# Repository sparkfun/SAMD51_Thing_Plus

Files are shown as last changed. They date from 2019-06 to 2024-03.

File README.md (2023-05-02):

SparkFun SAMD51 Thing Plus
========================================

SparkFun SAMD51 Thing Plus

[*SparkFun SAMD51 Thing Plus (DEV-14713)*](https://www.sparkfun.com/products/14713)

With a 32-bit ARM Cortex-M4F MCU, the [SAMD51 Thing Plus](https://www.sparkfun.com/products/14713) is one of our most powerful microcontroller boards yet! The SAMD51 Thing Plus provides you with an economical and easy to use development platform if you're needing more power with minimal working space. This Thing even comes flashed with the same convenient UF2 bootloader as the RedBoard Turbo. To make the Thing Plus even easier to use, we've moved a few pins around to make the board Feather compatible and it utilizes our handy Qwiic Connect System which means no soldering or shields are required to connect it to the rest of your system!

The ATSAMD51J20 utilizes a 32-bit ARM Cortex-M4 processor with Floating Point Unit (FPU), running up to 120MHz, up to 1MB of flash memory, up to 256KB of SRAM with ECC, up to 6 SERCOM interfaces, and other features. In addition to the USB interface and Qwiic connection, a The SAMD51 Thing Plus provides a 600mA 3.3V regulator and LiPo charger.

Repository Contents
-------------------

* **/Documentation** - Documentation (datasheet, graphical datasheet, etc.)
* **/Hardware** - Eagle design files (.brd, .sch)
* **/Production** - Production panel files (.brd)

Documentation
--------------
* [**Hookup Guide**](https://learn.sparkfun.com/tutorials/samd51-thing-plus-hookup-guide) - Basic hookup guide for the SAMD51 Thing Plus.
* [**SAMD51 Datasheet**](https://github.com/sparkfun/SAMD51_Thing_Plus/blob/master/Documents/SAMD51_datasheet.pdf)- Datasheet for the SAMD51 chip.
* [**Graphical Datasheet**](https://github.com/sparkfun/SAMD51_Thing_Plus/blob/master/Documents/SAMD51_Thing_Plus_graphical_datasheet_v01-02.pdf)- Graphical datasheet for the SAMD51 Thing Plus.

Product Versions
----------------
* [DEV-14713](https://www.sparkfun.com/products/14713) - Initial release of the SAMD51 Thing Plus.

Version History
---------------
* [V_1.0](https://github.com/sparkfun/SAMD51_Thing_Plus/releases/tag/v1.0.0) - Initial release of the SAMD51 Thing Plus.

License Information
-------------------

This product is _**open source**_! 

Please review the LICENSE.md file for license information.

If you have any questions or concerns on licensing, please visit the [SparkFun Forum](https://forum.sparkfun.com/index.php) and post a topic.

Distributed as-is; no warranty is given.

- Your friends at SparkFun.

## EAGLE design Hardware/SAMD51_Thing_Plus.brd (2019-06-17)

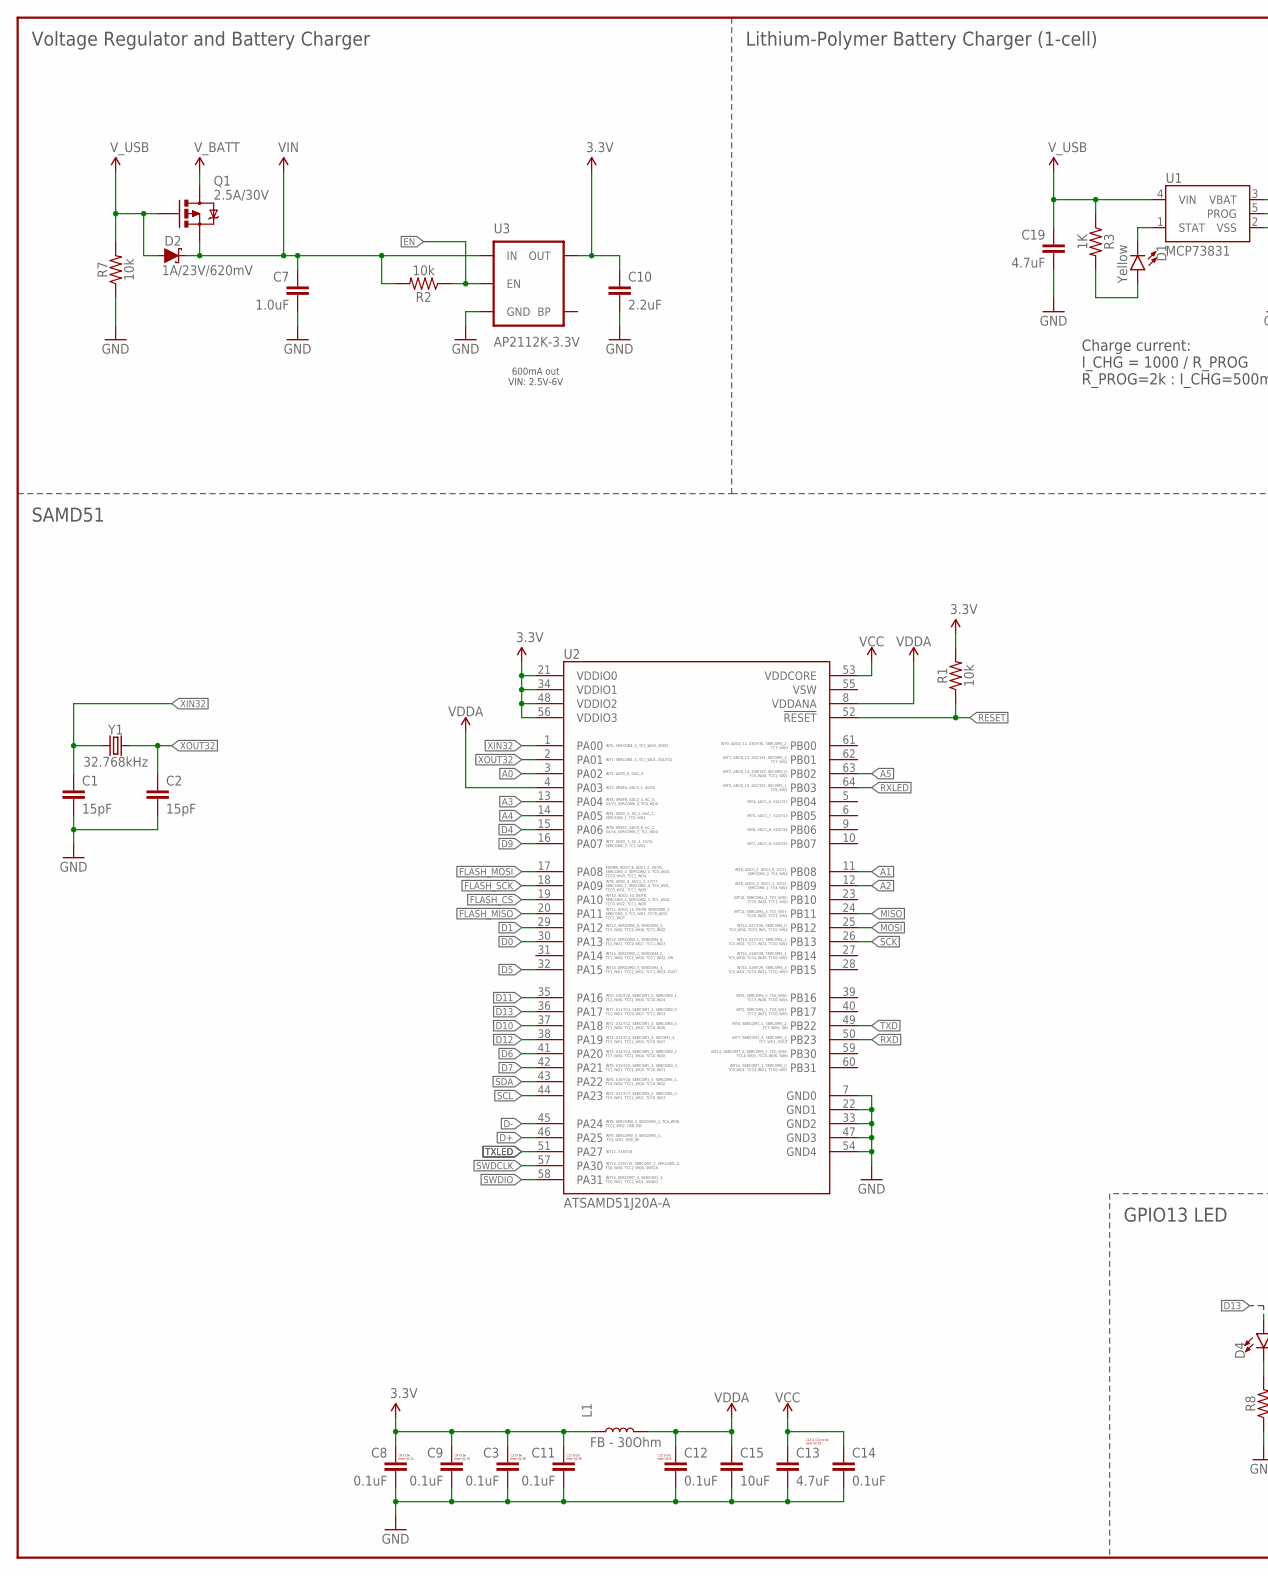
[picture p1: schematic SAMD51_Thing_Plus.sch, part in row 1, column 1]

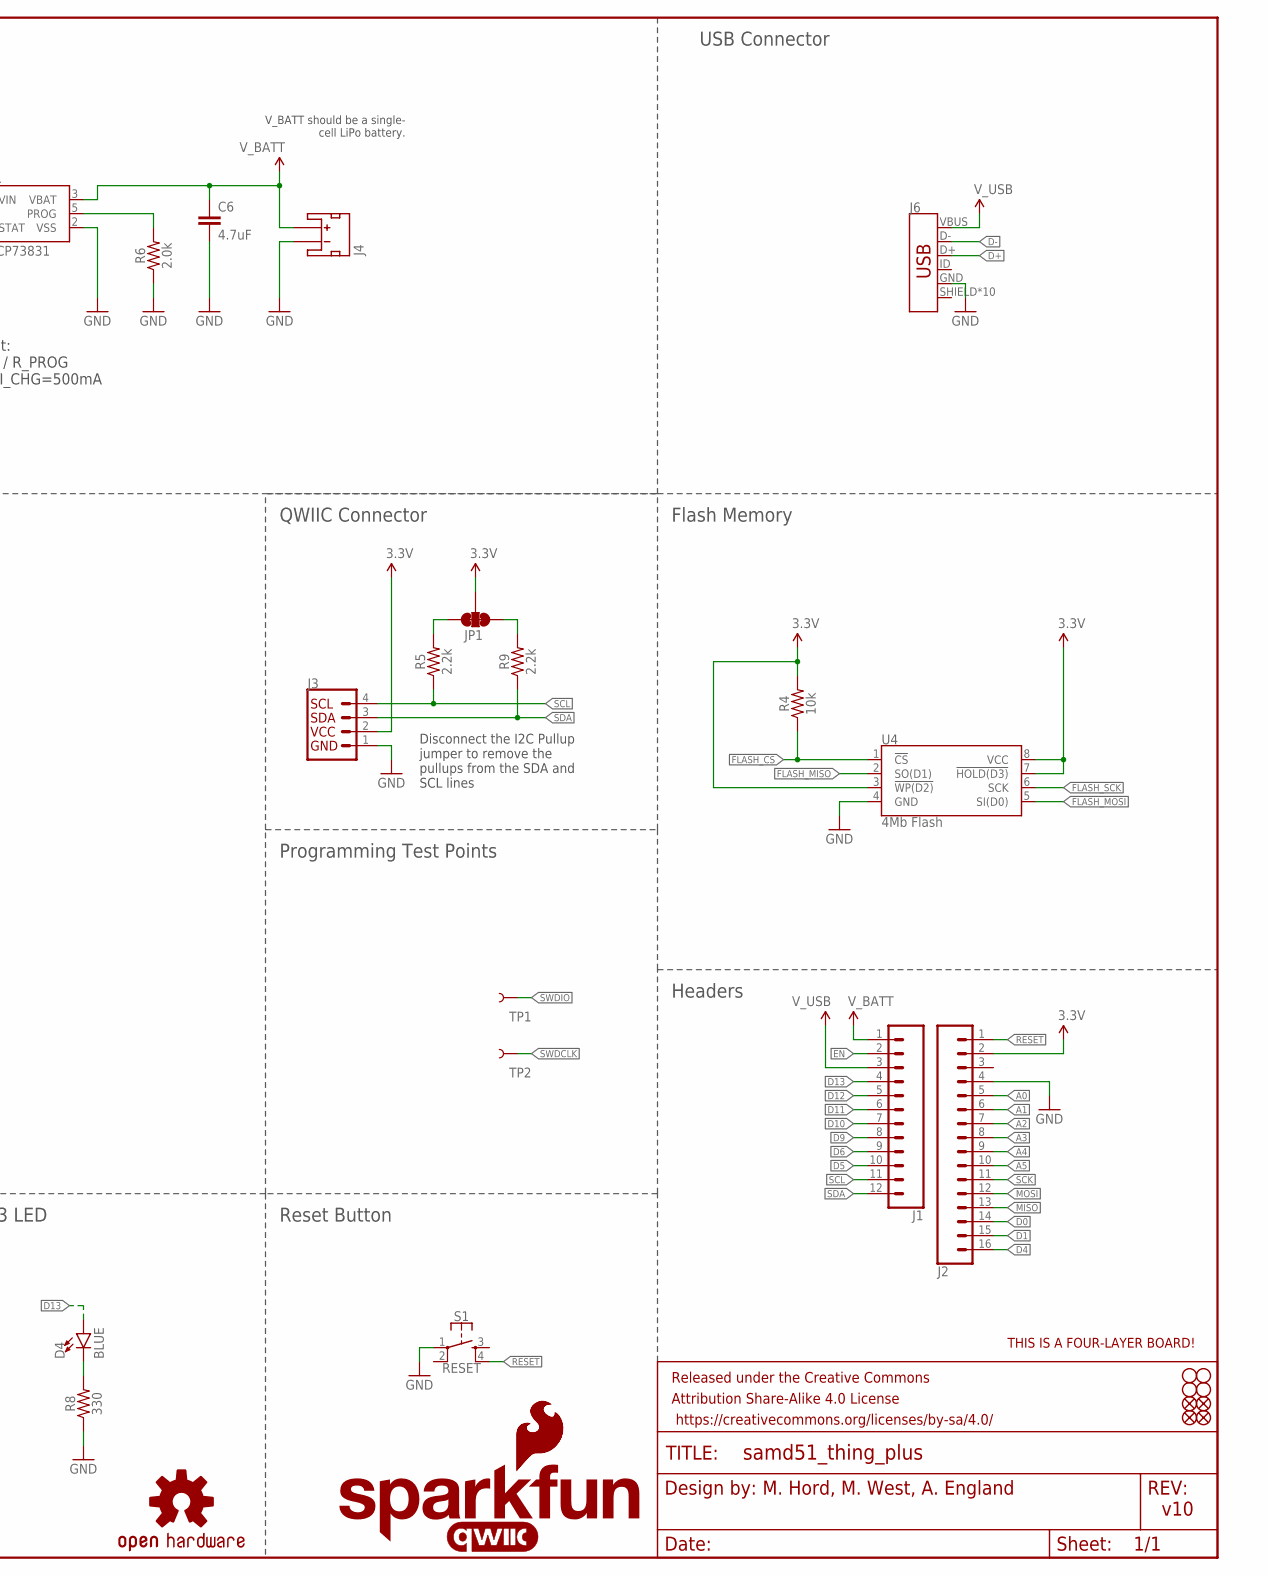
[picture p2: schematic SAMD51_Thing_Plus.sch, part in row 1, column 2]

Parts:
C1, C2: 15pF; 0402
C3, C8, C9, C11, C12, C14: 0.1uF; 0402
C6, C13, C19: 4.7uF; 0603
C7: 1.0uF; 0603
C10: 2.2uF; 0603
C15: 10uF; 0805
D1: Yellow; LED-0603
D2: 1A/23V/620mV; SOD-323
D4: BLUE; LED-0603
FD1, FD2, FD3, FD4: FIDUCIALUFIDUCIAL; FIDUCIAL-MICRO
FRAME1: FRAME-LEDGER; CREATIVE_COMMONS
H1, H2, H3, H4: STAND-OFF
J1: CONN_12SM_SQ_NO_SILK; 1X12_SM_SQ_NOSILK
J2: CONN_161X16_SM_SQ_NOSILK; 1X16_SM_SQ_NOSILK
J3: QWIIC_CONNECTORJS-1MM; JST04_1MM_RA
J4: JST_2MM_MALE; JST-2-SMD
J6: AMP FCI 10103594-0001LF; USB-MICROB-PTH-MILL
JP1: JUMPER-SMT_3_2-NC_TRACE_SILK; SMT-JUMPER_3_2-NC_TRACE_SILK
L1: FB - 30Ohm; 0603
LOGO1: FOUR_LAYER_WARNING
LOGO2: OSHW-LOGOMINI; OSHW-LOGO-MINI
LOGO3: SFE_LOGO_NAME_FLAME.1_INCH; SFE_LOGO_NAME_FLAME_.1
LOGO4: SFE_LOGO_FLAME.1_INCH; SFE_LOGO_FLAME_.1
Q1: 2.5A/30V; SOT23-3@1
R1, R2, R4, R7: 10k; 0603
R3: 1K; 0603
R5, R9: 2.2k; 0603
R6: 2.0k; 0603
R8: 330; 0603
S1: RESET; TACTILE_SWITCH_SMD_4.6X2.8MM
TP1, TP2: TEST-POINTTP_15TH_THRU; TP_15TH
U1: MCP73831; SOT23-5
U2: ATSAMD51J20A-A; TQFP64
U3: AP2112K-3.3V; SOT23-5
U4: 4Mb Flash; SO08
U$69: QWIIC_LOGO_5MM; QWIIC_5MM
Y1: 32.768kHz; CRYSTAL-SMD-3.2X1.5MM

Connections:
3.3V: C3.1, C8.1, C9.1, C10.1, C11.1, J2.2, J3.2, JP1.2, L1.1, R1.2, R4.2, U2.21 (VDDIO0), U2.34 (VDDIO1), U2.48 (VDDIO2), U2.56 (VDDIO3), U3.5 (OUT), U4.3 (!WP(D2)), U4.7 (!HOLD(D3)), U4.8 (VCC)
!RESET: J2.1, R1.1, S1.4, U2.52 (!RESET)
A0: J2.5, U2.3 (PA02)
A1: J2.6, U2.11 (PB08)
A2: J2.7, U2.12 (PB09)
A3: J2.8, U2.13 (PA04)
A4: J2.9, U2.14 (PA05)
A5: J2.10, U2.63 (PB02)
D0: J2.14, U2.30 (PA13)
D1: J2.15, U2.29 (PA12)
D4: J2.16, U2.15 (PA06)
D5: J1.10, U2.32 (PA15)
D6: J1.9, U2.41 (PA20)
D7: U2.42 (PA21)
D9: J1.8, U2.16 (PA07)
D10: J1.7, U2.37 (PA18)
D11: J1.6, U2.35 (PA16)
D12: J1.5, U2.38 (PA19)
D13: D4.A, J1.4, U2.36 (PA17)
D+: J6.D+, U2.46 (PA25)
D-: J6.D-, U2.45 (PA24)
EN: J1.2, R2.1, U3.3 (EN)
FLASH_CS: R4.1, U2.19 (PA10), U4.1 (!CS)
FLASH_MISO: U2.20 (PA11), U4.2 (SO(D1))
FLASH_MOSI: U2.17 (PA08), U4.5 (SI(D0))
FLASH_SCK: U2.18 (PA09), U4.6 (SCK)
GND: C1.2, C2.2, C3.2, C6.2, C7.2, C8.2, C9.2, C10.2, C11.2, C12.2, C13.2, C14.2, C15.2, C19.2, J2.4, J3.1, J4.1 (-), J6.GND, R6.1, R7.1, R8.1, S1.1, U1.2 (VSS), U2.7 (GND0), U2.22 (GND1), U2.33 (GND2), U2.47 (GND3), U2.54 (GND4), U3.2 (GND), U4.4 (GND)
MISO: J2.13, U2.24 (PB11)
MOSI: J2.12, U2.25 (PB12)
unnamed: D4.C, R8.2
unnamed: JP1.3, R5.2
unnamed: JP1.1, R9.2
unnamed: D1.C, U1.1 (STAT)
unnamed: R6.2, U1.5 (PROG)
unnamed: D1.A, R3.2
RXD: U2.50 (PB23)
RXLED: U2.64 (PB03)
SCK: J2.11, U2.26 (PB13)
SCL: J1.11, J3.4, R5.1, U2.44 (PA23)
SDA: J1.12, J3.3, R9.1, U2.43 (PA22)
SWDCLK: TP2.P$1, U2.57 (PA30)
SWDIO: TP1.P$1, U2.58 (PA31)
TXD: U2.49 (PB22)
TXLED: U2.51 (PA27)
VCC: C13.1, C14.1, U2.53 (VDDCORE)
VDDA: C12.1, C15.1, L1.2, U2.4 (PA03), U2.8 (VDDANA)
VIN: C7.1, D2.C, Q1.2 (S), R2.2, U3.1 (IN)
V_BATT: C6.1, J1.1, J4.2 (+), Q1.3 (D), U1.3 (VBAT)
V_USB: C19.1, D2.A, J1.3, J6.VBUS, Q1.1 (G), R3.1, R7.2, U1.4 (VIN)
XIN32: C1.1, U2.1 (PA00), Y1.P$1 (1)
XOUT32: C2.1, U2.2 (PA01), Y1.P$2 (2)

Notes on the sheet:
V_BATT should be a single- cell LiPo battery.
Charge current: I_CHG = 1000 / R_PROG R_PROG=2k : I_CHG=500mA
Voltage Regulator and Battery Charger
Lithium-Polymer Battery Charger (1-cell)
600mA out VIN: 2.5V-6V
Reset Button
GPIO13 LED
Headers
v10
C8 to be near U2.21
C9 to be near U2.34
C3 to be near U2.48
C11 to be near U2.56
C12 to be near U2.8
C13 & C14 to be near U2.53
QWIIC Connector
SAMD51
USB Connector
M. Hord, M. West, A. England
Programming Test Points
Flash Memory
Disconnect the I2C Pullup jumper to remove the pullups from the SDA and SCL lines

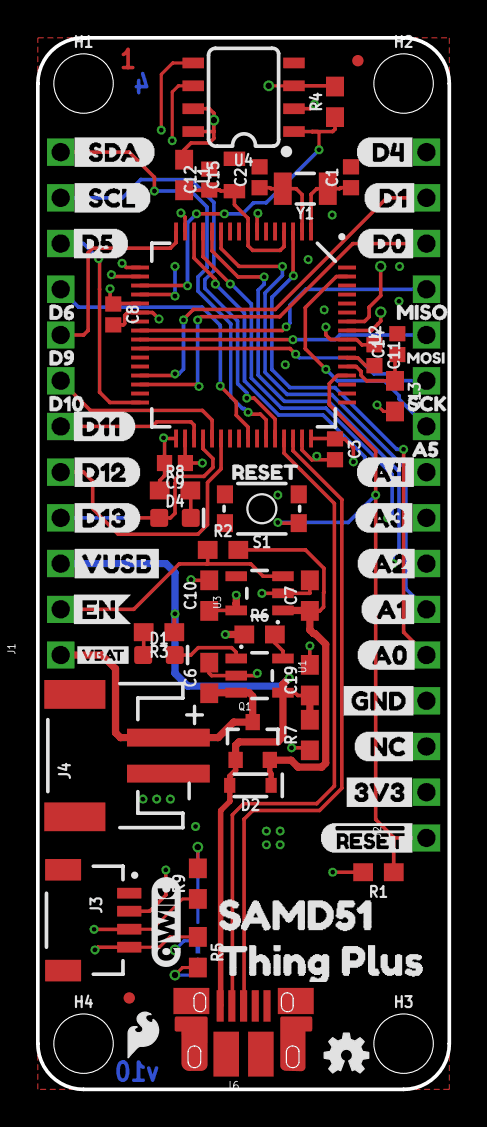
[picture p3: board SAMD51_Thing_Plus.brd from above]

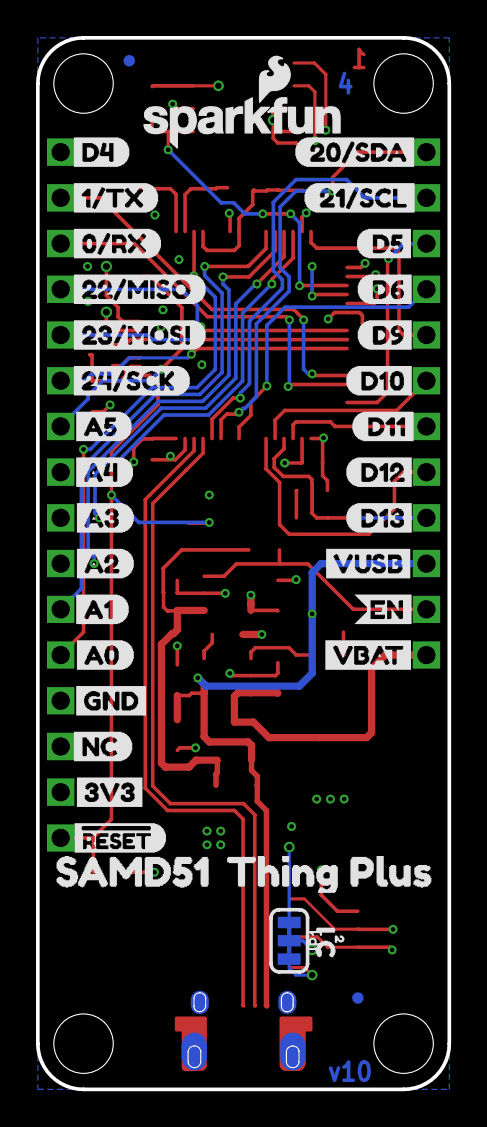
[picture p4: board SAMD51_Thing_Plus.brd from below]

Board: 4 copper layers, 22.9 x 58.4 mm, 120 parts (36 on the bottom side), 46 nets.

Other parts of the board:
U$4: RESET27
U$5: #RESET15
U$6: #RESET0
U$7: 3V32
U$8: A04
U$9: A15
U$10: A26
U$11: A37
U$12: A48
U$13: A523
U$14: SCK24
U$15: 3V33
U$16: MISO26
U$17: D09
U$18: D110
U$19: D411
U$20: GND3
U$21: GND0
U$22: EN0
U$23: VUSB2
U$24: D1312
U$25: D120
U$26: D1113
U$27: A014
U$28: A113
U$29: D515
U$30: _SCL16
U$31: ORDERING_INSTRUCTIONS
U$32: _SDA17
U$33: D63
U$34: D92
U$35: MOSI0
U$36: VBAT1
U$37: A212
U$38: A311
U$39: A410
U$40: A59
U$41: 21#SCL1
U$42: 22#MISO4
U$43: 23#MOSI3
U$44: 1#TX1
U$46: D41
U$47: 24#SCK2
U$48: 0#RX0
U$49: D518
U$50: D619
U$51: D920
U$52: D1122
U$53: D1021
U$54: D1223
U$55: D1324
U$56: VUSB1
U$57: EN25
U$58: VBAT2
U$59: D100
U$60: NC0
U$61: NC1
U$62: 20#SDA0
U$63, U$65: SAMD510
U$64, U$66: THING_PLUS1
U$67: I_C0
U$68: 21

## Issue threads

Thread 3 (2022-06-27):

ReadMe.md references "SparkFun ESP32 Thing" -- NOT "SAMD51 Thing Plus"

VashJuan, 2022-06-27:
Is "SAMD51 Thing Plus" just a small modification of the ESP32 Thing, or ????

bboyho, 2023-05-02:
Hi, I just noticed your question when viewing some files in this repo.

I'm not sure where you are seeing the references to the ESP32 in the README.MD? The Thing and Thing Plus are just different form factors. I assume that the original engineer used the Thing footprint as a template to start before adjusting the design for the Thing Plus footprint. Both boards have different features depending on the microcontroller that is populated (two of the major differences: one is that the ESP32 can connect to the cloud via WiFi while the SAMD51 cannot; the SAMD51 also does not need a USB-to-serial converter to upload new code since it has a native USB) and the pin locations are different.

Closed 2023-05-02.

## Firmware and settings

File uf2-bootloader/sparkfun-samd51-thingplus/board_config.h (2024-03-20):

#ifndef BOARD_CONFIG_H
#define BOARD_CONFIG_H

#define VENDOR_NAME "SparkFun Electronics"
#define PRODUCT_NAME "SparkFun SAMD51 Thing+"
#define VOLUME_LABEL "51THINGBOOT"
#define INDEX_URL "https://www.sparkfun.com/products/14713"
#define BOARD_ID "SAMD51J20A-SparkFun-Thing-v0"

#define USB_VID 0x1B4F
#define USB_PID 0x0016

#define LED_PIN PIN_PA17

#define BOOT_USART_MODULE                 SERCOM2
#define BOOT_USART_MASK                   APBBMASK
#define BOOT_USART_BUS_CLOCK_INDEX        MCLK_APBBMASK_SERCOM2
#define BOOT_USART_PAD_SETTINGS           UART_RX_PAD1_TX_PAD0
#define BOOT_USART_PAD3                   PINMUX_UNUSED
#define BOOT_USART_PAD2                   PINMUX_UNUSED
#define BOOT_USART_PAD1                   PINMUX_PA13C_SERCOM2_PAD1
#define BOOT_USART_PAD0                   PINMUX_PA12C_SERCOM2_PAD0
#define BOOT_GCLK_ID_CORE                 SERCOM2_GCLK_ID_CORE
#define BOOT_GCLK_ID_SLOW                 SERCOM2_GCLK_ID_SLOW

#endif

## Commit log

2018-04-19 First commit for samd51
    [13336_esp32-thing-panel.v10.brd, ESP32_Thing_Plus.brd, SAMD51_Thing_Plus.brd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]
2018-04-25 Post review feedback and engineer checklist
    [SAMD51_Thing_Plus.brd, SAMD51_Thing_Plus.sch]
2018-04-25 Fixes from QC review
    [SAMD51_Thing_Plus.brd, SAMD51_Thing_Plus.sch]
2018-04-25 Replaced retired 1.0uF cap with new one
    [SAMD51_Thing_Plus.brd, SAMD51_Thing_Plus.sch]
2018-06-01 Original thing plus
    [SAMD51_Thing_Plus.brd]
2018-06-04 Buzzard Text
    [SAMD51_Thing_Plus.brd, SAMD51_Thing_Plus.sch]
2018-06-05 Add flash, buzzard labels
    [SAMD51_Thing_Plus.brd, SAMD51_Thing_Plus.sch]
2018-06-05 Changes from review
    [SAMD51_Thing_Plus.brd, SAMD51_Thing_Plus.sch]
2018-06-06 A few more changes to text labels on schematic
    [SAMD51_Thing_Plus.brd, SAMD51_Thing_Plus.sch]
2018-06-06 Changes from QC review
    [SAMD51_Thing_Plus.brd, SAMD51_Thing_Plus.sch]
2018-06-26 Convert labels to Fredoka, headers to smaller square pads
    [SAMD51_Thing_Plus.brd, SAMD51_Thing_Plus.sch]
2018-06-29 Fix SPI pinout for flash and header
    [SAMD51_Thing_Plus.brd, SAMD51_Thing_Plus.sch]
2018-06-29 Clear some errors
    [SAMD51_Thing_Plus.brd]
2018-07-06 Moving QWIIC connector, adding board name, moving bottom-placed capacitor to top
    [SAMD51_Thing_Plus.brd]
2018-07-23 updating version number
    [SAMD51_Thing_Plus.GBL, SAMD51_Thing_Plus.GBO, SAMD51_Thing_Plus.GBS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]
2019-01-15 connecting D4 to match feather footprint, removing short on USB connector
    [SAMD51_Thing_Plus.brd, SAMD51_Thing_Plus.sch]
2019-01-16 post checklist changes
    [SAMD51_Thing_Plus.brd, SAMD51_Thing_Plus.sch]
2019-01-16 adding i2c labels from double check
    [SAMD51_Thing_Plus.brd, SAMD51_Thing_Plus.sch]
2019-04-12 pre-design review changes
    [SAMD51_Thing_Plus.GBL, SAMD51_Thing_Plus.GBO, SAMD51_Thing_Plus.GBS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]
2019-04-18 engineer run of checklist-REDS
    [SAMD51_Thing_Plus.brd, SAMD51_Thing_Plus.sch]
2019-04-19 post qc checklist
    [SAMD51_Thing_Plus.sch]
2019-05-24 Update to correct information
    Updated from ESP32 information
2019-06-17 Correct Label in Schematic
    - The Dev board was incorrectly labeled as 4MB in the schematic. It is technically 4Mb after checking the BOM.
    [SAMD51_Thing_Plus.brd, SAMD51_Thing_Plus.sch]
2021-08-02 updated documentation
    Fixed sercom and interrupt values on pin 13/LED
2021-10-05 Add original bootloader binaries
    Add the original Sparkfan SAMD51 Thing Plus bootloader binaries to the
    Thing Plus repo to keep more pieces of the product together.
    These files were copied from
    https://github.com/sparkfun/Arduino_Boards/commit/921656dcec4a28d10c3ff9c6128fa23f269c7568
2021-10-06 Fix automatic reset into bootloader
    The Arduino automatic flashing mechanism triggers a reboot into the
    bootloader by setting the UART to 1200 baud and then closing the
    connection. The Arduino framework code running on the microcontroller
    detects this change, sets a magic value in the last four bytes of SRAM
    and resets. The bootloader checks for this magic value and remains in
    the bootloader if it's present, otherwise it jumps to the application
    code. It's essential for the address and magic value to be in sync
    between the application code and the bootloader for this mechanism to
    work.
    On the SAMD51 Thing Plus, the Arduino framework application code writes
    the magic value to 0x2003fffc, but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
2021-10-06 Add uf2-samdx1 board config and updated bootloader
    Since the board config used to build the original bootloader appears
    to have been lost, this commit includes a reconstructed board config.
    Importantly, this board config also corrects the microcontroller model
    to SAMD51J20A.
    VENDOR_NAME was copied from the SAMD51 MicroMod board config.
    INDEX_URL links to the SAMD51 Thing Plus product page.
    PRODUCT_NAME and BOARD_ID were copied from INFO_UF2.TXT in
    bootloader mode.
    VOLUME_LABEL, USB_VID, and USB_PID were copied from the device
    details in bootloader mode.
    LED_PIN was set using the SAMD51 Thing Plus graphical datasheet.
    BOOT_USART_* was configured for the pins broken out as D0 (RX) and
    D1 (T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
    [board_config.h]
2023-05-02 Update graphical datasheet
    Fixes pin labels for RX/TX (swapped)

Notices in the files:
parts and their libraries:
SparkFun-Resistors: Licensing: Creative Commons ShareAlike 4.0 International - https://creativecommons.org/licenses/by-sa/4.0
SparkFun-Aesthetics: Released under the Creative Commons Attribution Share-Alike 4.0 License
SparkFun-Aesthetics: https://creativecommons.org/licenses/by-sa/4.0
